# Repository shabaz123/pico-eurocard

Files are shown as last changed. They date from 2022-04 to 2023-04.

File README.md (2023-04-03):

# pico-eurocard

This repository contains PCB Gerber files and bill of materials for a [Pi Pico Eurocard Development Board](https://community.element14.com/products/raspberry-pi/b/blog/posts/pi-pico-eurocard-development-board). See James' [Workshop Wednesday's Video](https://community.element14.com/challenges-projects/element14-presents/workbenchwednesdays/w/documents/28083/workbench-wednesdays-70-why-you-need-a-raspberry-pi-pico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) which demonstrates the revision 2.0 board.

Right-click below to open in new window to watch the video for a quick explanation!

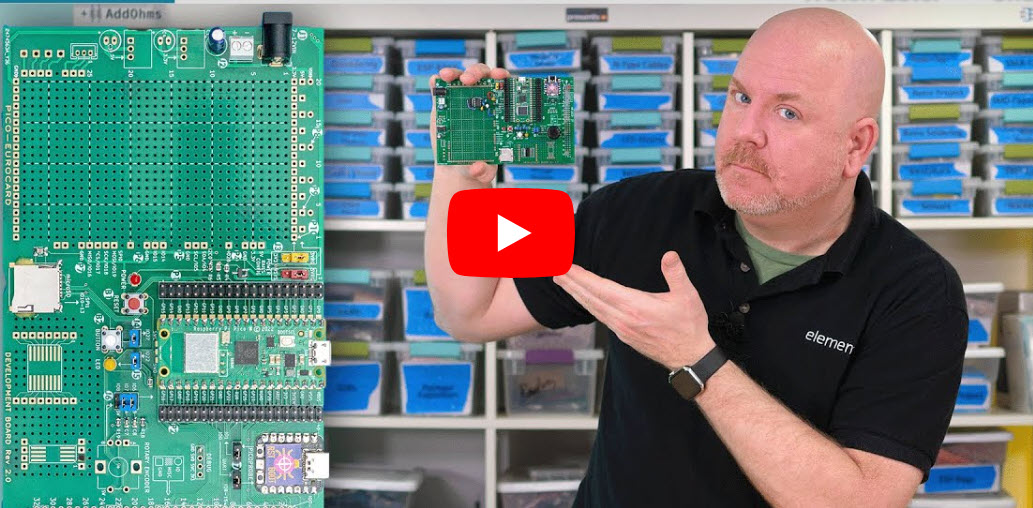
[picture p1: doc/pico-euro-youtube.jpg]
[](https://www.youtube.com/watch?v=-Kv5MwaRqbk "Pico-EUROCARD YouTube Video")

The current revision 2.2 board has a few slight impromements to make it easier to solder, and has enlarged text silkscreen as can be seen in the image below.

Latest [Schematic](https://github.com/shabaz123/pico-eurocard/blob/main/pico-euro-kicad-source/pico-euro-schematic.pdf) and [Bill of Materials](https://github.com/shabaz123/pico-eurocard/blob/main/pico-euro-kicad-source/pico-euro-rev-2-2-bill-of-materials.pdf) and [Zip file of Gerbers](https://github.com/shabaz123/pico-eurocard/blob/main/export_pico_euro_rev_2_2.zip), (click on the Download button on the right) ready for sending to any PCB factory.

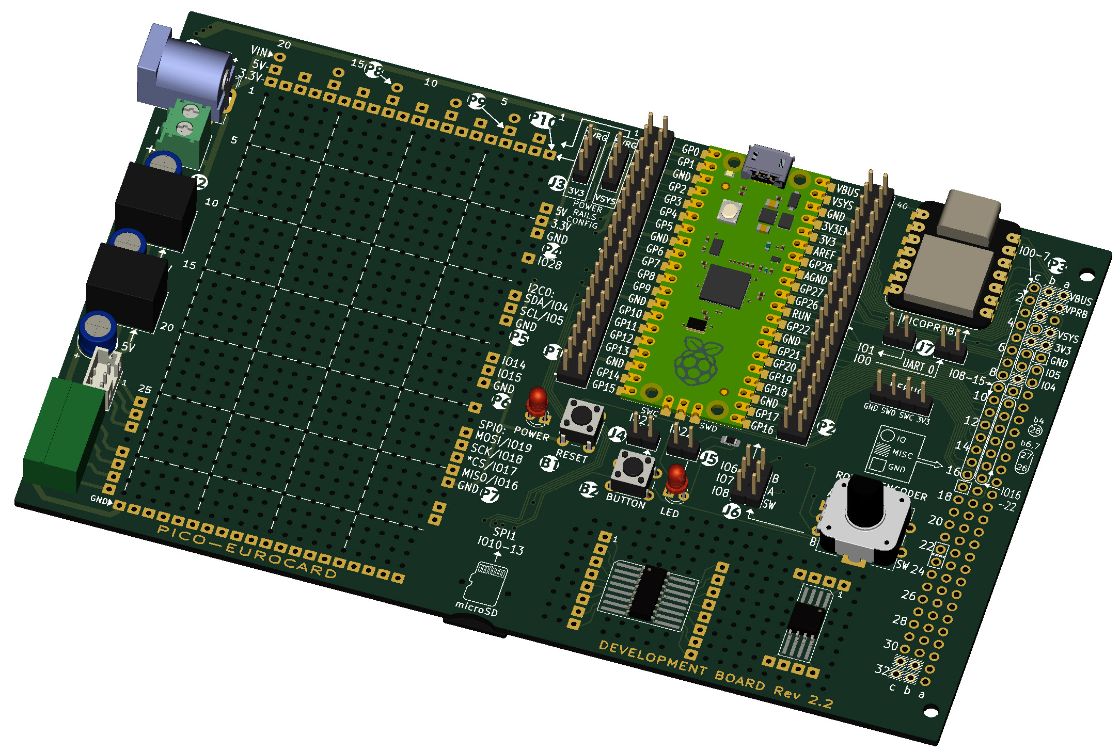
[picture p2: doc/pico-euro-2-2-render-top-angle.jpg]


License: The pico-eurocard project is distributed under the CC BY-NC-SA 4.0 license. Please share any changes you make, so that others can contribute and benefit from them.

Board Revision History

Rev 1 - Resistors R2 and R3 are mistakenly connected to GND. They should be connected to 3V3. See the rev1-i2c-fix.png file to see the fix (requires two traces to be cut, and a wire to be soldered).

Rev 1.1 - Fixes the R2 and R3 issue that Rev 1 had. Also adds connections for an SPI TFT display, and exposes I2C, GND and VSYS onto some additional pins on the edge connector for some more flexibility. Also, the 7805 regulator has a bit more space, to allow heatsinks to more easily fit.

Rev 1.2 - Adds some pads on the underside of the SOIC footprints, that are suitable for decoupling capacitors, and for optional output feedback components if the soldered SOIC component is an op-amp. Also, the corners of the board have been rounded very slightly (0.5 mm radius). Previously, the corners had no radius.

Rev 1.3 - Added some pads to make it slightly easier to plug on a daughter board made from (say) stripboard.

Rev 2.0 - Removed SPI TFT pins, since there was some incompatibility with recently available displays. Added micro SD card socket.

Rev 2.2 - Very similar to 2.0 version, but with far more legible silkscreen, and with all surface-mount components (including the micro SD socket) on one side of the board, for easier production. Also added a resistor for more gate protection with partially assembled boards.

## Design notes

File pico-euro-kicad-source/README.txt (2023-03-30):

Please see the following links for more information on this project, and to comment on it:

https://community.element14.com/products/raspberry-pi/b/blog/posts/pi-pico-eurocard-development-board

https://community.element14.com/challenges-projects/element14-presents/workbenchwednesdays/w/documents/28083/workbench-wednesdays-70-why-you-need-a-raspberry-pi-pico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

https://community.element14.com/tags/pico_5F00_eurocard

Software Links:
https://github.com/jancumps/picoprobe/releases

https://github.com/shabaz123/rp2040tools

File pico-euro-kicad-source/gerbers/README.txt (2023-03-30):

The zip file can be directly uploaded to PCB factories, e.g. JLC PCB, Elecrow, etc.

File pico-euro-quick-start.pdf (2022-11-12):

# Quick Start

## Getting Started

1. Plug in a Pico (you can solder it in, but more preferable to use SIL connectors, so that you can later unplug and swap with Pico Wireless for instance.
2. Plug in a USB cable to the Pico, and start coding : ) No other connections or configuration needed. Some popular methods to work with the Pico are:
3. It’s not too easy to unplug the Pico! I use a blunt-edged plastic item (like a pen) and lever it out.

## Using the Built-in Button and LED

If the GPIO conflicts with any other circuit you are assembling, then you can unplug the shorting jumpers that are near the button and LED, to disconnect them.

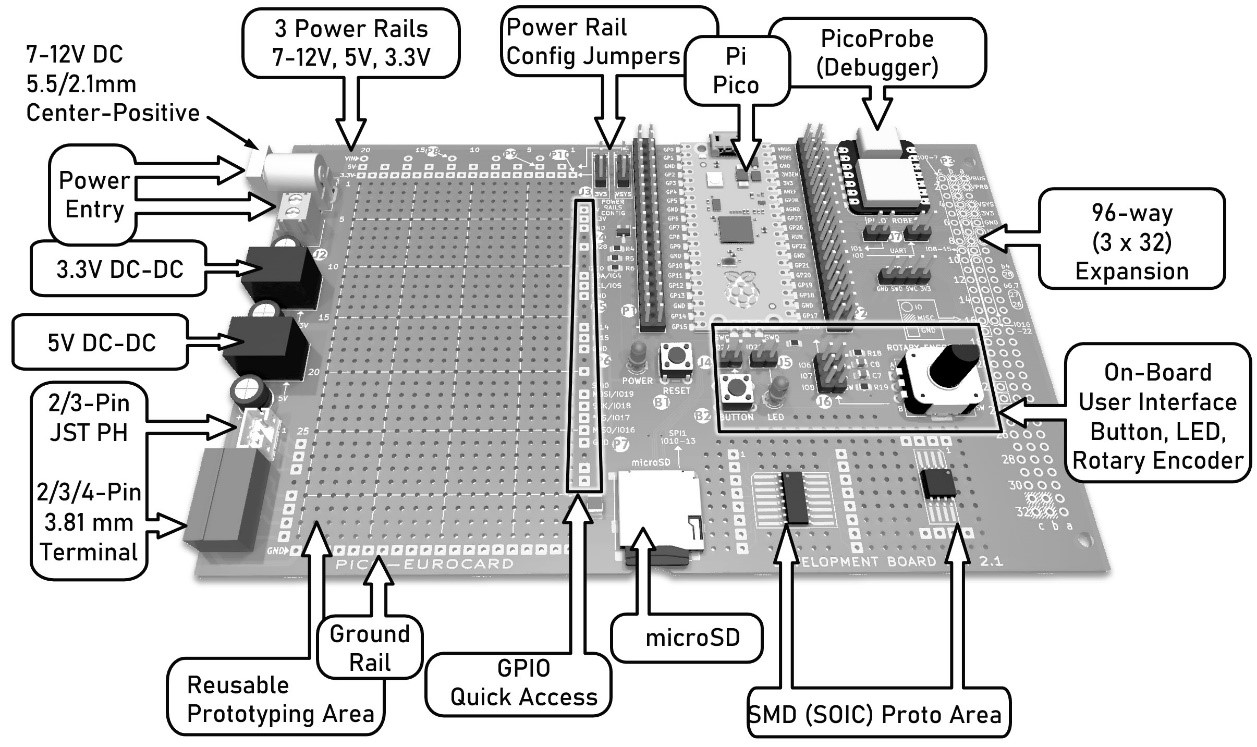
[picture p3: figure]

## Using the Prototyping Area

1. The Power Rail Config Jumpers (labelled J3 on the board) are used to control the 5V and 3.3V power rails on the prototype area of the board. Here are the settings (there is a diagram in the For Reference section):
a. When the jumpers are in the lower position, then the power rails are derived from the Pico USB connection. This is the normal setting.
b. When the jumpers are in the upper position, then the rails are derived from an external power source (the Power Entry connectors on the left side of the board) via Voltage Regulators (DC-DC converters); this is described in step 2. You can continue to use the USB cable too; there is no harm in simultaneously connecting the supply and the USB cable.
2. If you want to power the board from a 7-12V source, then you can use the Power Entry connectors (J1 or J2), provided a 5V Voltage Regulator (DC-DC converter) is installed. The barrel connector is 5.5/2.1mm with centerpositive. You can also optionally add a 3.3V regulator if you need more current than the Pico can provide. You can see the locations of the regulators on the left side of the board. As mentioned, set the Power Rail Config Jumpers to the upper position to set the prototyping area power rails to use the regulators.

C/C++ using
Arduino IDE

MicroPython
using Thonny

CircuitPython
using Mu
Editor

C/C++ SDK

Button B2
GPIO27

LED
GPIO22

3. Depending on preference, you could either solder parts to the prototyping area (they are easy to desolder and reuse the area), and just patch wires using either jumper cables or directly soldered wires, or you could connect a SIL connector to the GPIO Quick Access column (labelled P4,P5,P6,P7), and then plug on an external board, such as stripboard.
4. The GPIO Quick Access column provides access to some popular GPIO. The 5V and 3.3V supplies are also available on that column, to make it convenient to plug on a daughter board.

## Using the Picoprobe Debugger

This section is only relevant for C/C++ SDK. You will need to install a 3-pin cable before you plug in the Pico, as described in the steps here:

1. The Picoprobe Debugger is very useful for working with the C/C++ SDK. It is not needed when working with Arduino IDE, or MicroPython or CircuitPython.
2. The Picoprobe Debugger is basically special firmware that runs on a separate RP2040 chip. For the Pico-Eurocard board, the XIAO RP2040 board is used. Solder the XIAO RP2040 onto the board, and then upload the Picoprobe firmware to it. It can be obtained here: https://github.com/shabaz123/rp2040tools
3. The Picoprobe connects to the target Pi Pico using a 3-wire connector. You can use the jumper cable supplied to do that. A jumper cable is used because different versions of the Pico (for instance the Pico W) have the connections in a different place on the Pico module.
4. Software development can be using the command line, or using an interactive development environment (IDE).
5. In terms of IDEs, you can use VS Code, or Jetbrains CLion to develop using the C/C++ SDK. Personally I find CLion easier, but others prefer VS Code. Both have their benefits/disadvantages.

### 6. To use VS Code, start with the blog here and follow the info/links:

https://community.element14.com/products/raspberry-pi/f/forum/51735/first-experience-with-a-raspberrypico---setup-toolchain-ide-debug-and-freertos

### 7. To use CLion the details are here: https://community.element14.com/products/raspberry-

pi/b/blog/posts/using-clion-for-easier-coding-with-pi-pico-and-c-c
8. The Picoprobe has its own USB Type C connector. It can get messy having to connect both the target Pi Pico Micro USB cable, and the Picoprobe Type C USB cable both into the PC (unless you’re actually developing a project that uses USB). You can actually power everything from the single Picoprobe Type C cable if you wish. To do that, connect a shorting jumper to the top-right of the board (labelled P3), to pins labelled VBUS and VPRB. If you use the VBUS-to-VPRB shorting jumper, then you shouldn’t connect up any other power supply, and ideally you shouldn’t connect both USB cables. It is best to disconnect the shorting jumper at all times unless you are powering everything from the Picoprobe Type C cable only. The VBUS/VPRB jumper is merely a convenience for the occasional times that you’re only interested in coding, and are not powering up the board from other sources.

## For Reference

Power Rail Config jumper diagram:

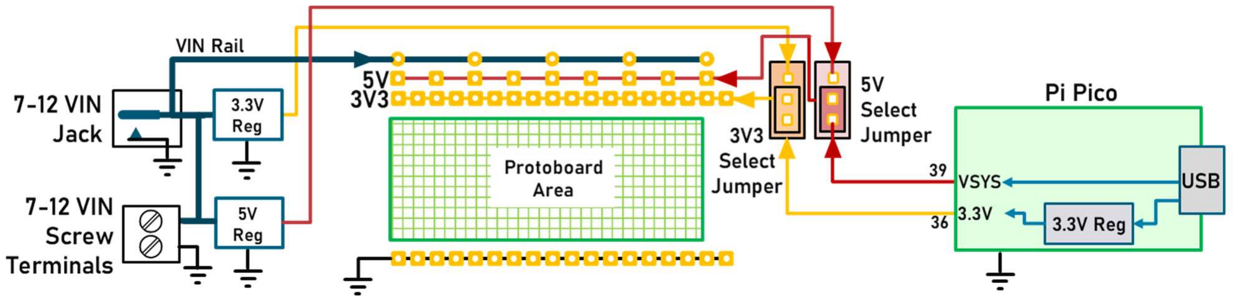
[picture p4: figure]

## Further Information

Search for pico_eurocard on the element14 website, there are articles there covering the hardware as well as some projects.

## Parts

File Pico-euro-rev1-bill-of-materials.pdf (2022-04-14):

## Pico-Eurocard Development Board Bill of Materials Rev 1.0

Item | Qty | Reference(s) | Value | Description
1 | 1 | C1 | 22u | Electrolytic Capacitor 6.3mm dia
2 | 1 | C2 | 100n | Capacitor 0805
3 | 1 | C3 | 2.2u | Electrolytic Capacitor 6.3mm dia
4 | 2 | D1, D2 | Red LED 3mm | User_Global_Symbol_Library:LED
5 | 2 | J2, J3 | DIL 40-way Pin Header | 2x20 DIL Pin Header 2.54mm
6 | 4 | J4, J5, J8, J20 | SIL 2-way Pin Header | 1x2 SIL Pin Header 2.54mm
7 | 1 | J6 | SIL 4-way Pin Header | 1x4 SIL Pin Header 2.54mm
8 | 1 | J7 | DC Jack Socket | Example is FC68148
9 | 1 | J9 | Screw Terminal 2-way | 3.5mm pitch Phoenix Contact Screw Terminal
10 | 1 | J21 | SIL 3-way Pin Header | 1x3 SIL Pin Header 2.54mm
11 | 1 | Q1 | Si2301 or FDV304P or IRLML2246 | SOT-23 P-ch MOSFET
12 | 3 | R1, R4, R6 | 100R | Resistor 0805
13 | 2 | R2, R3 | 10k | Resistor 0805
14 | 1 | R5 | 100k | Resistor 0805
15 | 2 | SW1, SW2 | RESET | Tact Switch 6x6mm
16 | 1 | U1 | Pi Pico | Pi Pico module
17 | 1 | U2 | MC7805CT | 7805 Voltage Regulator TO220
18 | 5 | n/a | Jumper | Shorting Jumper 2.54mm

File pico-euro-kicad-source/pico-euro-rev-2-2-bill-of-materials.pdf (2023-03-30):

## Pico-EuroCARD Rev 2.2 Bill of Materials

Board Underside, solder these first, in this order! (Q1 MOSFET is soldered last so it has a bit of protection. Observe ESD precautions!)
Designator | Quantity | Designation
R22 | 1 | 220k 0805 Resistor
R2, R3, R5, R16, R17, R18, R19 | 7 | 10k 0805 Resistor
R1, R4, R6, R7, R8 | 5 | 100 ohm 0805 Resistor
R20, R21 | 2 | 0R Resistor
R9, R10, R11, R12, R13, R14,
R15

### 7 Do Not Fit (DNF)

C2,C5 | 2 | 100n 0805 Capacitor X7R 16V
C7,C8 | 2 | 10n 0805 Capacitor
C6 | 1 | 1u 1210 Capacitor X7R 10V
J40 | 1 | Optional MicroSD Socket, example is Molex 502774-0891, might need some epoxy glue
Q1 | 1 | P-ch MOSFET Si2301 or FDV304P or IRLML2246 (SOT-23)

Board Topside, solder in the order shown, or any order that makes sense
Designator | Quantity Designation
N/A | 2 | Pin Header Single Row 20 way for Pico
N/A | 2 | Pin Header Right Angle Single Row 3-way for SWD connections
N/A | 6 | Crimp Sockets 2226TG (Farnell/Newark) for assembling SWD cable
N/A | 2 | Connector Housing 3-way SIL 2226A-03 (Farnell/Newark) for assembling SWD cable
U3 | 1 | XIAO RP2040
N/A | 2 | SIL sockets 2212S-20SG-85 (cheap) or 801-87-036-10-001101 (luxury)
N/A | 2 | Pin Header Single Row 40 way (cut as required)
SW1, SW2 | 2 | Tact Push Switch, 6 x 6mm (ideally 1 x red for reset, and 1 x any other color)
D1 | 1 | 3mm LED Amber
D2 | 1 | 3mm LED Red
N/A | 1 | Pin Header Dual Row 6 way (2x3)
C3, C4 | 2 | 10u 16V Electrolytic Capacitor, 6.3mm dia, 2.5mm pitch
C1 | 1 | 22u 16V Electrolytic Capacitor 6.3mm dia 2.5mm pitch
J9 | 1 | Screw Terminal Block 3.5 mm pitch 2-way
J7 | 1 | Barrel DC Power Socket 2.1mm with flat pins, example is FC68148
U2 | 1 | Recom R-78E5.0-0.5 (5V DC-DC Converter)
U4 | 1 | Recom R-78E3.3-0.5 (3.3V DC-DC Converter)
J2, J3 | 2 | Pin Header Dual Row 40 way (2x20)
U1 | 1 | Pi Pico (original or Pico-W wireless version)
J15 | 1 | Optional Screw Terminal Block, 3.81mm, 4 way
SW3 | 1 | Rotary Encoder Alps EC12E, example is EC12E24104A6
N/A | 10 | 2.54mm Jumpers (Ideally 1 x Orange, 2 x Red, 7 x Blue or Black)

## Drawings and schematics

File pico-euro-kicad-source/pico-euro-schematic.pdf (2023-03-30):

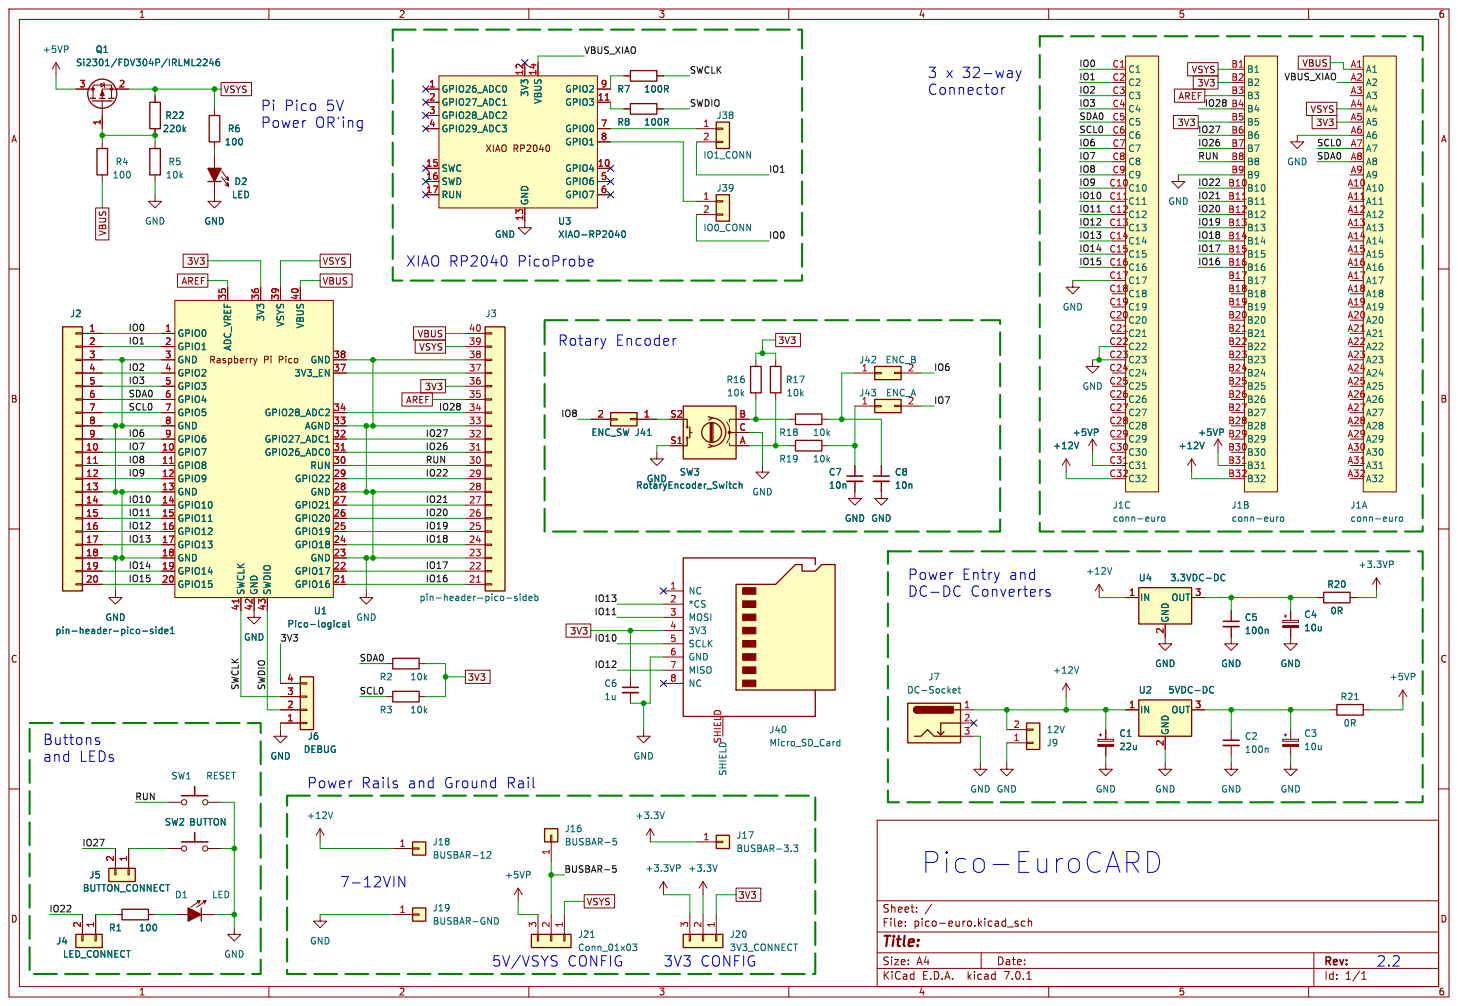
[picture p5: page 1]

GND
Power Rails and Ground Rail

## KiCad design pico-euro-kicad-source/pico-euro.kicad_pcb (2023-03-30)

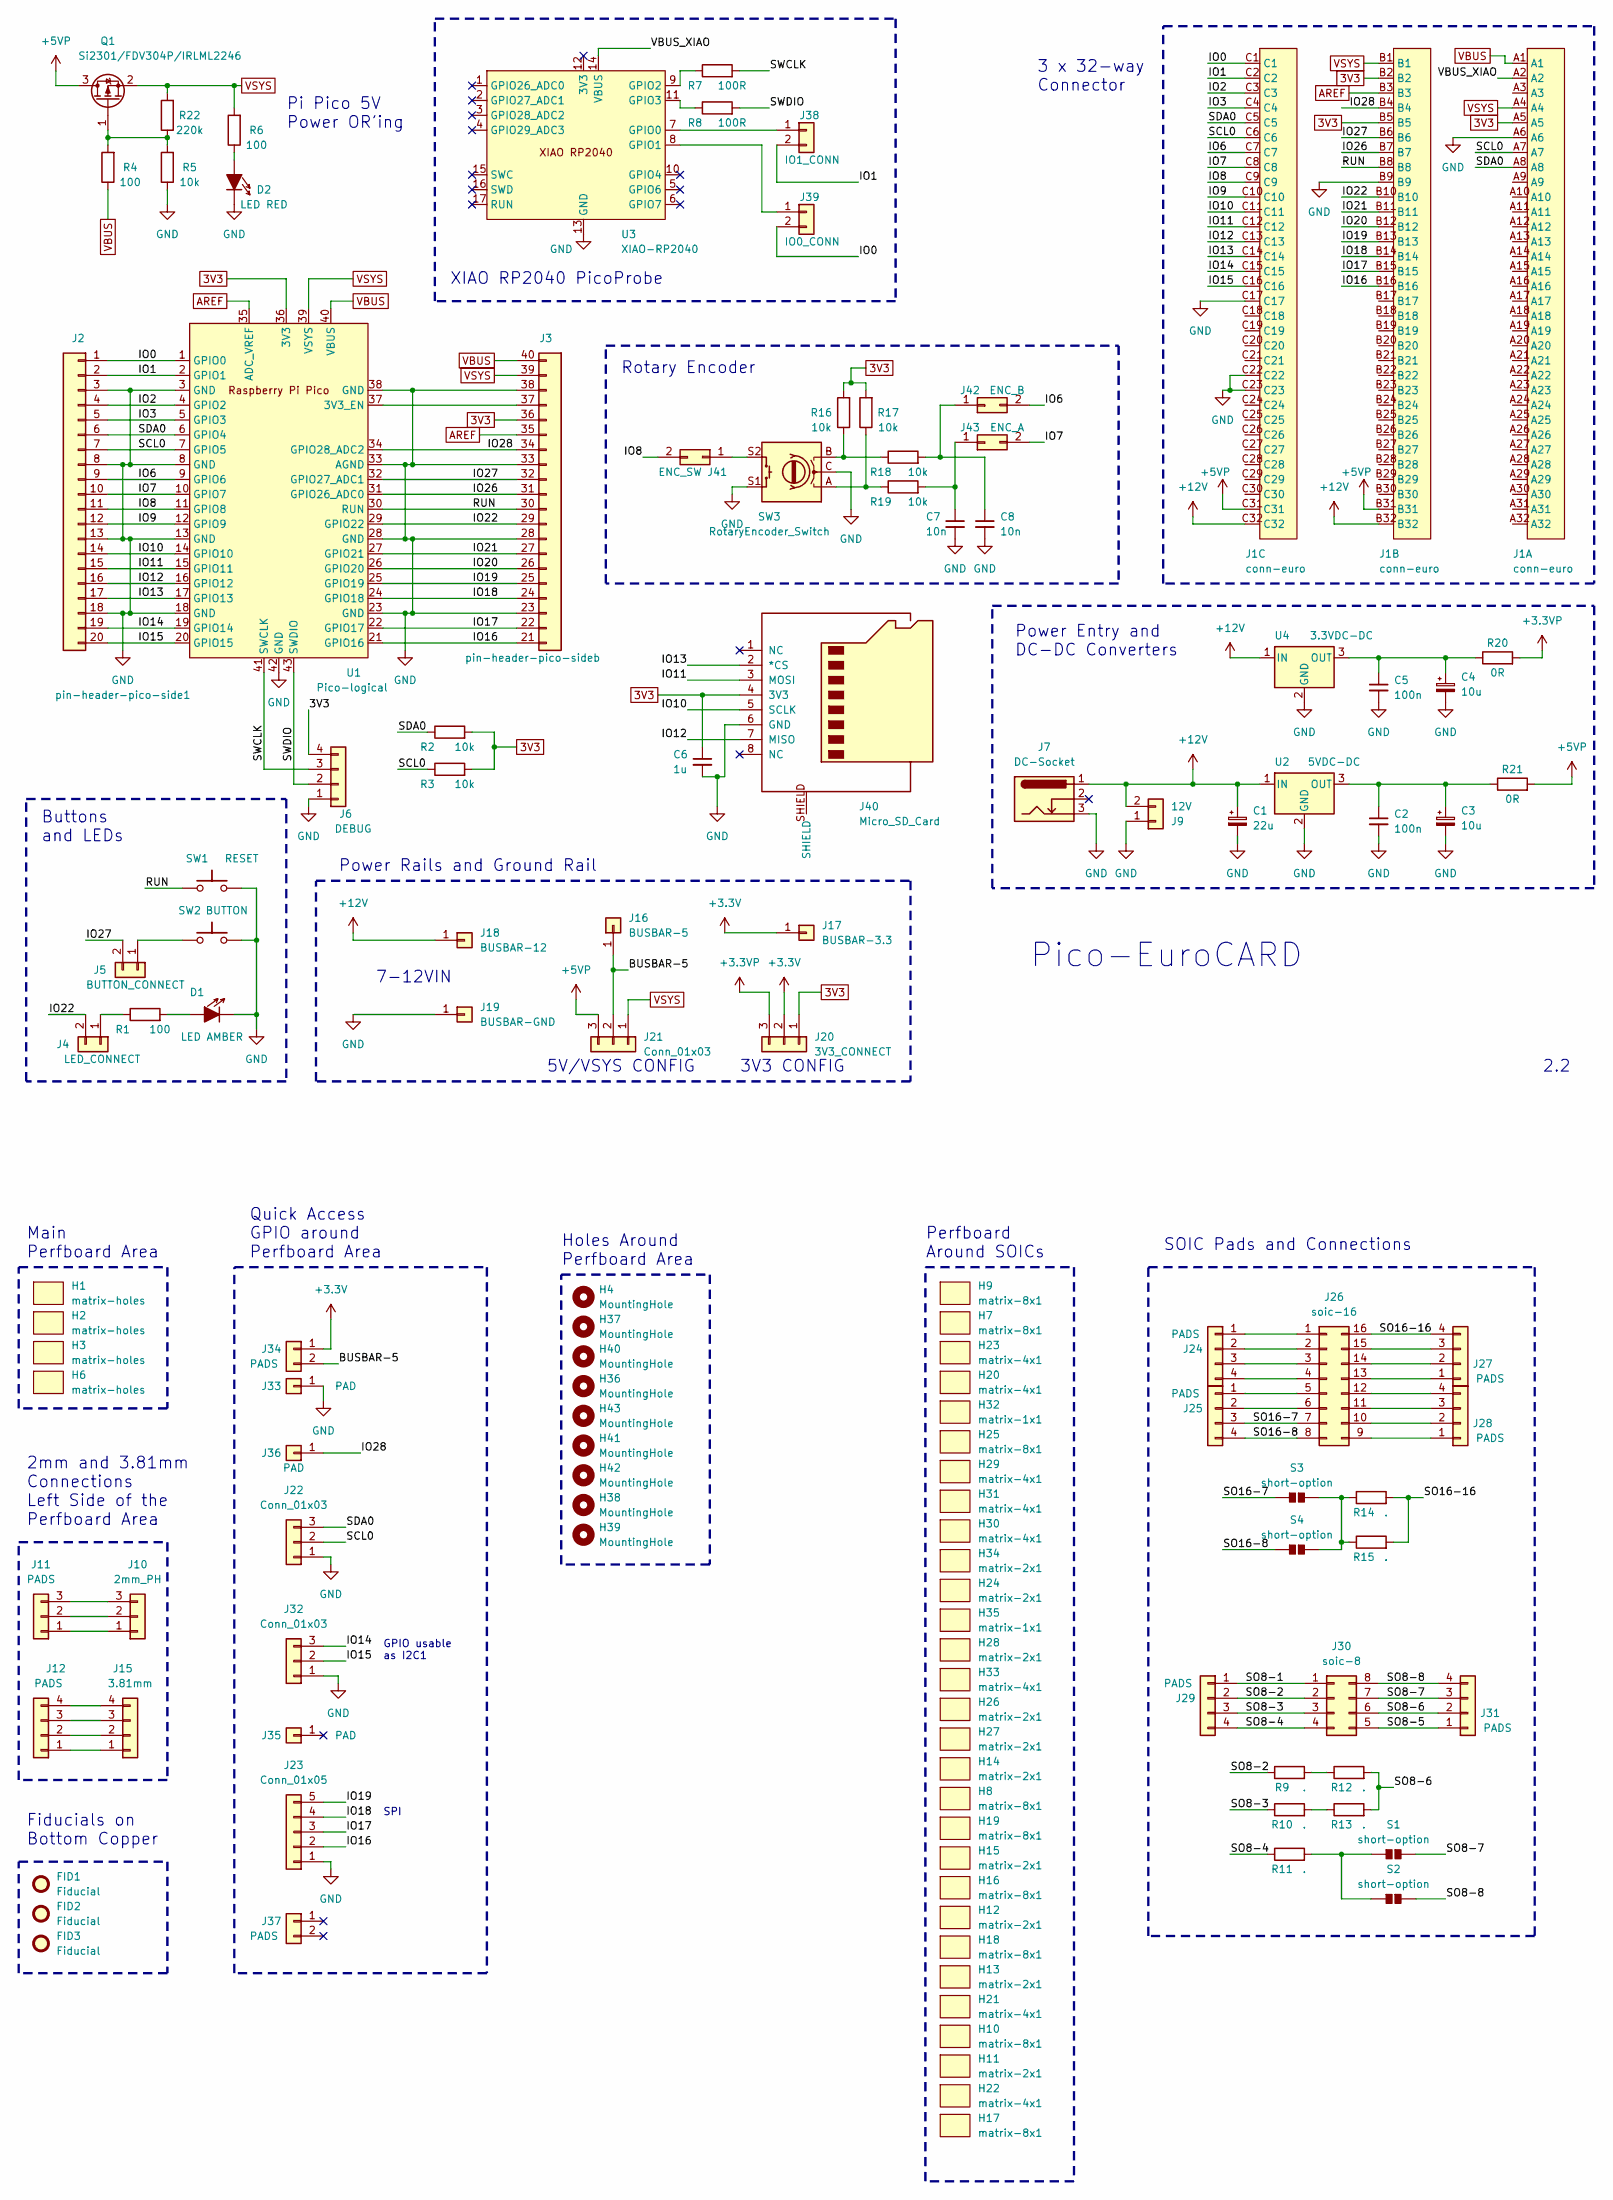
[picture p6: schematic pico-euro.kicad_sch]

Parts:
C1: 22u; CP_Radial_D6.3mm_P2.50mm
C2, C5: 100n; C_0805_2012Metric_Pad1.18x1.45mm_HandSolder
C3, C4: 10u; CP_Radial_D6.3mm_P2.50mm
C6: 1u; C_1210_3225Metric_Pad1.33x2.70mm_HandSolder
C7, C8: 10n; C_0805_2012Metric_Pad1.18x1.45mm_HandSolder
D1: LED AMBER; LED_D3.0mm
D2: LED RED; LED_D3.0mm
FID1, FID2, FID3: Fiducial; Fiducial_1mm_Mask2mm
H1, H2, H3, H6: matrix-holes; matrix-33-4
H4, H36, H37, H38, H39, H40, H41, H42, H43: MountingHole; HOLE_BARE_0.9mm
H7, H8, H9, H10, H16, H17, H18, H19, H25: matrix-8x1
H11, H12, H13, H14, H15, H24, H26, H27, H28, H34: matrix-2x1
H20, H21, H22, H23, H29, H30, H31, H33: matrix-4x1
H32, H35: matrix-1x1
J1: conn-euro; Eurocard-Plug-Type-C
J2: pin-header-pico-side1
J3: pin-header-pico-sideb; pin-header-pico-side2
J4: LED_CONNECT; PinHeader_1x02_P2.54mm_Vertical
J5: BUTTON_CONNECT; PinHeader_1x02_P2.54mm_Vertical
J6: DEBUG; PinHeader_1x04_P2.54mm_Vertical
J7: DC-Socket; DC-Jack-10
J9: 12V; TerminalBlock_Phoenix_PT-1,5-2-3.5-H_1x02_P3.50mm_Horizontal
J10: 2mm_PH; JST_PH_3_VERT
J11: PADS; pads3-euro
J12, J24, J25, J27, J28, J29, J31: PADS; pads4-euro
J15: 3.81mm; array-3.81
J16: BUSBAR-5; busbar-20div2
J17: BUSBAR-3.3; busbar-20
J18: BUSBAR-12; busbar-20div4
J19: BUSBAR-GND; busbar-20
J20: 3V3_CONNECT; PinHeader_1x03_P2.54mm_Vertical
J21: Conn_01x03; PinHeader_1x03_P2.54mm_Vertical
J22, J32: Conn_01x03; pads3-euro
J23: Conn_01x05; pads5-euro
J26: soic-16; SOIC-16-proto
J30: soic-8; SOIC-8-proto
J33, J35, J36: PAD; pads1-euro
J34, J37: PADS; pads2-euro
J38: IO1_CONN; PinHeader_1x02_P2.54mm_Vertical
J39: IO0_CONN; PinHeader_1x02_P2.54mm_Vertical
J40: Micro_SD_Card; microsd-generic
J41: ENC_SW; PinHeader_1x02_slim
J42: ENC_B; PinHeader_1x02_slim
J43: ENC_A; PinHeader_1x02_slim
Q1: Si2301/FDV304P/IRLML2246; SOT-23_Handsoldering
R1, R4, R6: 100; R_0805_2012Metric_Pad1.20x1.40mm_HandSolder
R2, R3, R5, R16, R17, R18, R19: 10k; R_0805_2012Metric_Pad1.20x1.40mm_HandSolder
R7, R8: 100R; R_0805_2012Metric_Pad1.20x1.40mm_HandSolder
R9, R10, R11, R12, R13, R14: .; R_0805_2012Metric_Pad1.20x1.40mm_HandSolder
R15: .; R_1210_3225Metric_Pad1.30x2.65mm_HandSolder
R20, R21: 0R; R_0805_2012Metric_Pad1.20x1.40mm_HandSolder
R22: 220k; R_0805_2012Metric_Pad1.20x1.40mm_HandSolder
S1, S2, S3, S4: short-option; short-option-small
SW1: RESET; SW_PUSH_6mm
SW2: BUTTON; SW_PUSH_6mm
SW3: RotaryEncoder_Switch; Encoder-and-Switch
U1: Pico-logical; pi-pico-euro
U2: 5VDC-DC; DCDC-78xx-replacement
U3: XIAO-RP2040
U4: 3.3VDC-DC; DCDC-78xx-replacement

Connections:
3V3: C6.1, J1.A5, J1.B2, J1.B5, J3.36, J6.4, J20.1, J40.4 (3V3), R2.2, R3.2, R16.2, R17.2, U1.36 (3V3)
+3.3VP: J20.3, R20.2
+3V3: J17.1, J20.2, J34.1
+5VP: J1.B31, J1.C31, J21.3, Q1.3 (D), R21.2
+12V: C1.1, J1.B32, J1.C32, J7.1, J9.2, J18.1, U2.1 (IN), U4.1 (IN)
/BUSBAR-5: J16.1, J21.2, J34.2
/IO0: J1.C1, J2.1, J39.2, U1.1 (GPIO0)
/IO1: J1.C2, J2.2, J38.2, U1.2 (GPIO1)
/IO2: J1.C3, J2.4, U1.4 (GPIO2)
/IO3: J1.C4, J2.5, U1.5 (GPIO3)
/IO6: J1.C7, J2.9, J42.2, U1.9 (GPIO6)
/IO7: J1.C8, J2.10, J43.2, U1.10 (GPIO7)
/IO8: J1.C9, J2.11, J41.2, U1.11 (GPIO8)
/IO9: J1.C10, J2.12, U1.12 (GPIO9)
/IO10: J1.C11, J2.14, J40.5 (SCLK), U1.14 (GPIO10)
/IO11: J1.C12, J2.15, J40.3 (MOSI), U1.15 (GPIO11)
/IO12: J1.C13, J2.16, J40.7 (MISO), U1.16 (GPIO12)
/IO13: J1.C14, J2.17, J40.2 (*CS), U1.17 (GPIO13)
/IO14: J1.C15, J2.19, J32.3, U1.19 (GPIO14)
/IO15: J1.C16, J2.20, J32.2, U1.20 (GPIO15)
/IO16: J1.B16, J3.21, J23.2, U1.21 (GPIO16)
/IO17: J1.B15, J3.22, J23.3, U1.22 (GPIO17)
/IO18: J1.B14, J3.24, J23.4, U1.24 (GPIO18)
/IO19: J1.B13, J3.25, J23.5, U1.25 (GPIO19)
/IO20: J1.B12, J3.26, U1.26 (GPIO20)
/IO21: J1.B11, J3.27, U1.27 (GPIO21)
/IO22: J1.B10, J3.29, J4.2, U1.29 (GPIO22)
/IO26: J1.B7, J3.31, U1.31 (GPIO26_ADC0)
/IO27: J1.B6, J3.32, J5.2, U1.32 (GPIO27_ADC1)
/IO28: J1.B4, J3.34, J36.1, U1.34 (GPIO28_ADC2)
/RUN: J1.B8, J3.30, SW1.1, U1.30 (RUN)
/SCL0: J1.A7, J1.C6, J2.7, J22.2, R3.1, U1.7 (GPIO5)
/SDA0: J1.A8, J1.C5, J2.6, J22.3, R2.1, U1.6 (GPIO4)
/SO8-1: J29.1, J30.1
/SO8-2: J29.2, J30.2, R9.1
/SO8-3: J29.3, J30.3, R10.1
/SO8-4: J29.4, J30.4, R11.1
/SO8-5: J30.5, J31.1
/SO8-6: J30.6, J31.2, R12.2, R13.2
/SO8-7: J30.7, J31.3, S1.2 (A)
/SO8-8: J30.8, J31.4, S2.2 (A)
/SO16-7: J25.3, J26.7, S3.1 (K)
/SO16-8: J25.4, J26.8, S4.1 (K)
/SO16-16: J26.16, J27.4, R14.2, R15.2
/SWCLK: J6.3, R7.2, U1.41 (SWCLK)
/SWDIO: J6.2, R8.2, U1.43 (SWDIO)
/VBUS_XIAO: J1.A2, U3.14 (VBUS)
AREF: J1.B3, J3.35, U1.35 (ADC_VREF)
GND: C1.2, C2.2, C3.2, C4.2, C5.2, C6.2, C7.2, C8.2, D1.1 (K), D2.1 (K), J1.A6, J1.B9, J1.C17, J1.C22, J1.C23, J2.3, J2.8, J2.13, J2.18, J3.23, J3.28, J3.33, J3.38, J6.1, J7.3, J9.1, J19.1, J22.1, J23.1, J32.1, J33.1, J40.6 (GND), R5.1, SW1.2, SW2.2, SW3.C, SW3.S1, U1.3 (GND), U1.8 (GND), U1.13 (GND), U1.18 (GND), U1.23 (GND), U1.28 (GND), U1.33 (AGND), U1.38 (GND), U1.42 (GND), U2.2 (GND), U3.13 (GND), U4.2 (GND)
unnamed: D1.2 (A), R1.2
unnamed: D2.2 (A), R6.1
unnamed: J3.37, U1.37 (3V3_EN)
unnamed: J4.1, R1.1
unnamed: J5.1, SW2.1
unnamed: J10.1, J11.1
unnamed: J10.2, J11.2
unnamed: J10.3, J11.3
unnamed: J12.1, J15.1
unnamed: J12.2, J15.2
unnamed: J12.3, J15.3
unnamed: J12.4, J15.4
unnamed: J24.1, J26.1
unnamed: J24.2, J26.2
unnamed: J24.3, J26.3
unnamed: J24.4, J26.4
unnamed: J25.1, J26.5
unnamed: J25.2, J26.6
unnamed: J26.9, J28.1
unnamed: J26.10, J28.2
unnamed: J26.11, J28.3
unnamed: J26.12, J28.4
unnamed: J26.13, J27.1
unnamed: J26.14, J27.2
unnamed: J26.15, J27.3
unnamed: J38.1, U3.7 (GPIO0)
unnamed: J39.1, U3.8 (GPIO1)
unnamed: J41.1, SW3.S2
unnamed: C8.1, J42.1, R18.2
unnamed: C7.1, J43.1, R19.2
unnamed: Q1.1 (G), R4.2, R5.2, R22.1
unnamed: R10.2, R13.1
unnamed: R9.2, R12.1
unnamed: R16.1, R18.1, SW3.B
unnamed: R17.1, R19.1, SW3.A
unnamed: R11.2, S1.1 (K), S2.1 (K)
unnamed: R14.1, R15.1, S3.2 (A), S4.2 (A)
unnamed: C2.1, C3.1, R21.1, U2.3 (OUT)
unnamed: R7.1, U3.9 (GPIO2)
unnamed: R8.1, U3.11 (GPIO3)
unnamed: C4.1, C5.1, R20.1, U4.3 (OUT)
VBUS: J1.A1, J3.40, R4.1, U1.40 (VBUS)
VSYS: J1.A4, J1.B1, J3.39, J21.1, Q1.2 (S), R6.2, R22.2, U1.39 (VSYS)

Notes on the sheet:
3V3 CONFIG
Quick Access GPIO around Perfboard Area
5V/VSYS CONFIG
Buttons and LEDs
Rotary Encoder
Holes Around Perfboard Area
7-12VIN
Pi Pico 5V Power OR'ing
Perfboard Around SOICs
Power Entry and DC-DC Converters
Pico-EuroCARD
Power Rails and Ground Rail
XIAO RP2040 PicoProbe
Main Perfboard Area
Fiducials on Bottom Copper
2mm and 3.81mm Connections Left Side of the Perfboard Area
3 x 32-way Connector
GPIO usable as I2C1
SOIC Pads and Connections
2.2
SPI

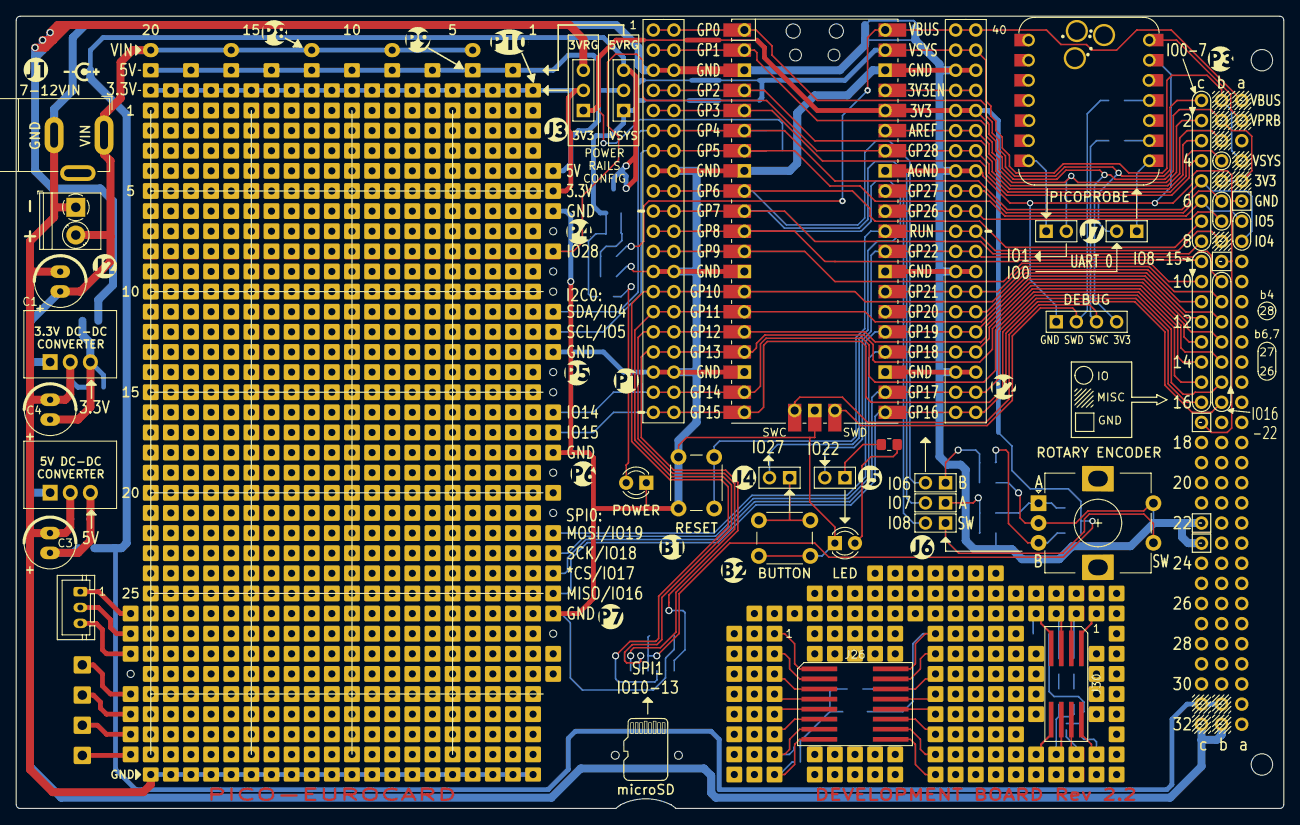
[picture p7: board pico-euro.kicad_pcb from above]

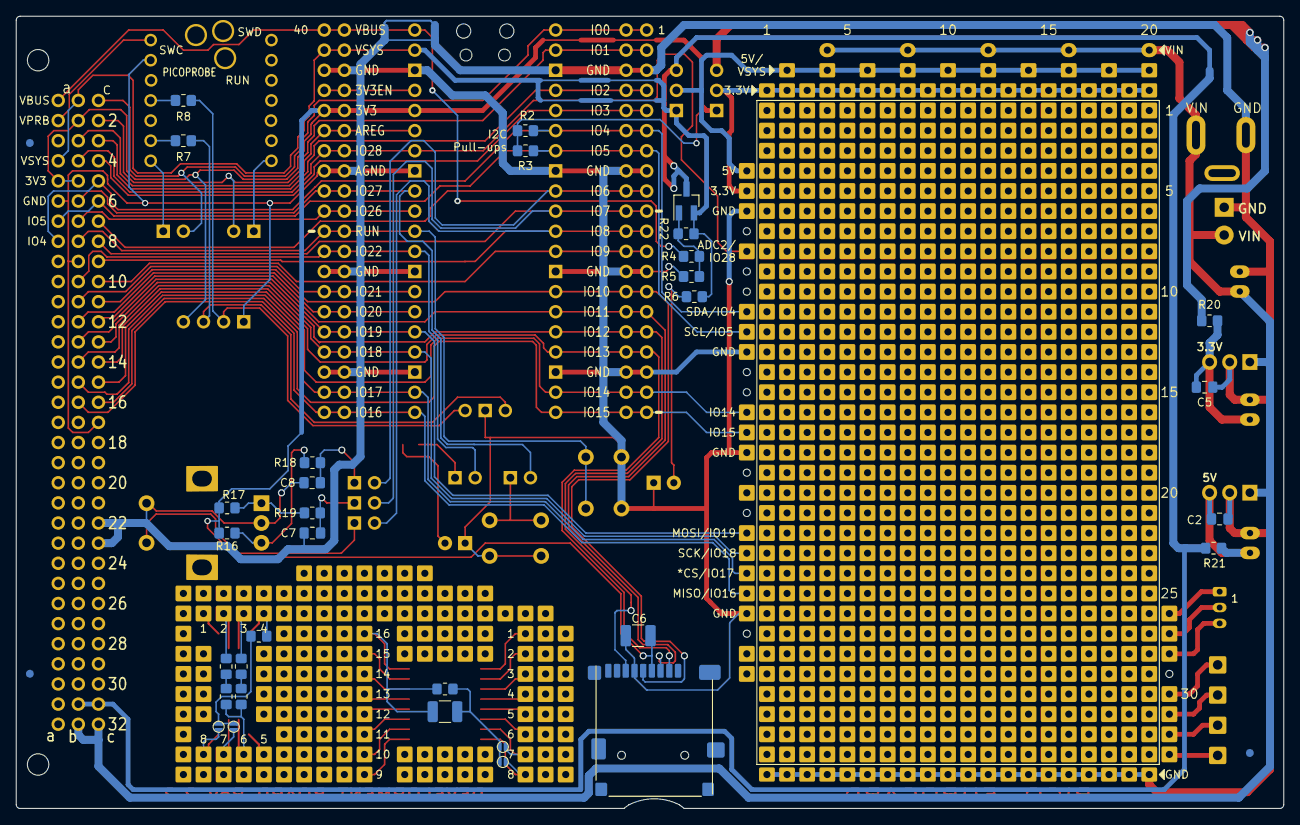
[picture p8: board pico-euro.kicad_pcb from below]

Board: 2 copper layers, 160.0 x 100.0 mm, 129 parts (68 on the bottom side), 92 nets.

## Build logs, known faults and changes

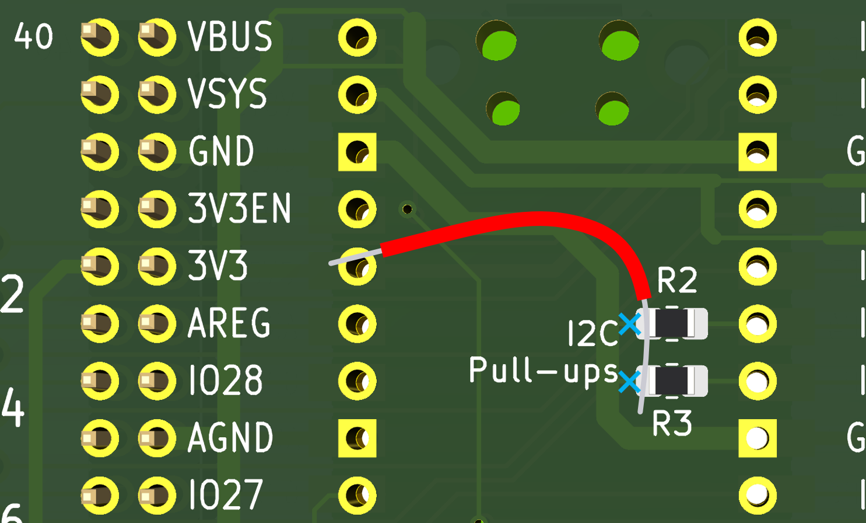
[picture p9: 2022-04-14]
rev1-i2c-fix.png
